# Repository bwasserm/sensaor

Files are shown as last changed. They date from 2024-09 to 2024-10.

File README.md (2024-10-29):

# senSAOr - a sensor SAO

A Simple Add-On (SAO) for a conference badge with a modular sensor port and a reactive multicolor LED.

# Project Goals
* Design and make an SAO in time for Hackaday Supercon 2024
* Make it inexpensive enough and simple enough to make a bunch and trade with others
* Blinky, but more interesting than only blinky
* Cool design
* If writing firmware, write it in Rust
* If using a microcontroller, use RISC-V

# High Level Design

SAO is a microcontroller that reads a sensor from an input pin, and uses the measured voltage to drive the color/brightness/pattern of an LED.
Create ports for multiple different sensors to be used, with the ability to solder in different signal conditioning.
Use ID pins or a solderable resistors to tell firmware how to "read" the sensor and drive the LED in response.

# Expected Behaviors

The inputs are read to set the color of the bottom LED. Every cycle, the colors are clocked one LED up the board, and potentially out to an attached strand of addition WS2812s attached at the top. All inputs are read in [0V, 3.3V] as low to high.

## Red/Green/Blue
These inputs are read to set the base intensity of the LEDs accordingly.

## Speed
This sets the delay between update cycles from fast (low) to slow (high). Full low has no added delay between cycles, and full high has about 1s between cycles.

## Shape
This is the mixture ration between setting the output intensity of the colors based directly on the input (low) vs also mixing in a sine wave (high) to the brightness (off to the intensity set by the color input).

## Phase
When mixing in the sine wave, this delays the mix of the sine wave applied to green and blue relative to red. Low is the same phase of sine wave is applied to all three colors, and high is about 120 degrees of delay to green and 240 degrees of delay to blue.

## ID pins
Currently unused

## I2C
Currently unused. Set as high impedance inputs.

## GPIO\[12\]
Currently unused. Set as high impedance inputs.

## More WS2812
Connect more Neopixels here to continue clocking out colors beyond the three on the SAO.

## SAOAO
Hopefully "standard" SAOAO port to connect an SAOAO.

# Resources
* [Shitty Add-On Version 2.0 Specification](https://docs.google.com/document/u/0/d/1EJqvkkLMAPsQ9VWF5A4elWoi0qMlKyr5Giw5rqRmtnM/mobilebasic?pli=1)
* [Opensource toolchain for WCH CH32V RISC-V 32bit MCU](https://github.com/cjacker/opensource-toolchain-ch32v)
* [ch32-hal](https://github.com/ch32-rs/ch32-hal)
* [Rust on the CH32V003](https://noxim.xyz/blog/rust-ch32v003/)
* [CH32V00X-hal](https://github.com/ch32-rs/ch32v00x-hal)
* [wlink application](https://github.com/ch32-rs/wlink)
* [wlink with CH32V003](https://github.com/ch32-rs/wlink/blob/main/docs/CH32V003.md)
* [CH32V003F4P6-R0 image](https://github.com/openwch/ch32v003/blob/main/SCHPCB/CH32V003F4P6-R0-1v1/image/board1.jpg)
* [CH32V003F4P6-R0 schematic](https://github.com/openwch/ch32v003/blob/main/SCHPCB/CH32V003F4P6-R0-1v1/SCH_PCB/CH32V003F4P6-R0-1v1.pdf)
* [ch32v003.svd](https://github.com/ch32-rs/ch32-rs/blob/main/svd/fixed/ch32v003.svd)
* [CH32V003 Reference Manual](https://www.wch-ic.com/downloads/file/358.html)
* [CH32V003 Processor Manual](https://www.wch-ic.com/downloads/file/369.html)
* [CH32V003 Datasheet](https://www.wch-ic.com/downloads/file/359.html)
* [RISC-V Spec](https://riscv.org/wp-content/uploads/2019/12/riscv-spec-20191213.pdf)
* [SAOAO](https://hackaday.io/project/198060-yo-dawg-sao-introducing-saoao)

# Implementation blog

## Getting rust to build

Getting rust to compile was mostly following the [Rust on the CH32V003](https://noxim.xyz/blog/rust-ch32v003/) blog, with some off-roading. LLVM had already
picked up the support for `rv32ec` (the `e` extension is the core `i` architecture, but with 16 registers instead of 32 for smaller silicon), but rustc didn't know
the riscv32ec-unknown-none-elf target. Eventually I figured out I didn't need to make the hack to rustc either, if I provided a target .json file to build against.
However, having a local copy of llvm and the binary tools was useful, such as for llvm-objdump.

Eventually I found that much of the work on the blog was "done" in the [CH32V00X-hal](https://github.com/ch32-rs/ch32v00x-hal) project, so I cloned that next to this project.
To avoid copying files, I hacked this to link to it. .cargo/config.toml points the target to `ch32v00x-hal/riscv32ec-unknown-none-elf.json`. The target json I copied from the noxim
blog is included for good measure.

I also found that the `-Tmemory.x` and `-Tlink.x` arguments got redundant with the CH32V00X-hal repo and build.rs (adding that repo as a Cargo dep changes things), so it may
require some experimentation.

Note on `memory.x`:
Looking at the memory map, it appears that program flash is a 16KB block starting at address `0x0800 0000`. However, ch32v00x-hal and the noxim blog both define
`FLASH (rx) : ORIGIN = 0x00000000, LENGTH = 16K` at address `0x0000 0000`, which is the `Aliased to Flash or system memory depending on software configuration` block of a much
larger size. This block defaults to flash, and the program counter (`pc`) will default to address `0x0000 0000` when the chip boots. So even though it seems unintuitive, set the `FLASH`
address in `memory.x` to be 0x0. 

I went down an exploratory path using `ch32v00x-hal/link-qkv2.x` instead of finding `link.x`, which required modifying `INCLUDE device.x` to become `INCLUDE svd2rs/device.x`,
after also `cargo install svd2rust`, and running it on [cj32v003.svd](https://github.com/ch32-rs/ch32-rs/blob/main/svd/fixed/ch32v003.svd) to generate `device.x`. However, after
adding in [CH32V00X-hal](https://github.com/ch32-rs/ch32v00x-hal), I found I didn't need this.

## Getting blinky to run

I'm playing with the CH32V003F4P6-R0 dev board, pictured [here](https://github.com/openwch/ch32v003/blob/main/SCHPCB/CH32V003F4P6-R0-1v1/image/board1.jpg), and referencing
the [schematic](https://github.com/openwch/ch32v003/blob/main/SCHPCB/CH32V003F4P6-R0-1v1/SCH_PCB/CH32V003F4P6-R0-1v1.pdf) as well was super handy. Especially because I tried using
PA1 as an arbitrary GPIO pin choice, but it is already tied to the oscillator.

I used the [wlink](https://github.com/ch32-rs/wlink) application with the WLinkE . It turned out to be surprisingly easy to run and use to dump registers and flash. It's not even
necessary to convert the elf file produced by cargo/rustc into an Intel Hex file or a bin first.

```
cargo install wlink
```

* Programming command: `sudo ~/.cargo/bin/wlink -v --chip ch32v003 flash target/riscv32ec-unknown-none-elf/debug/sensaor`
* Get registers command: `sudo ~/.cargo/bin/wlink -v --chip ch32v003 regs`
* Dump the beginning of program flash: `sudo ~/.cargo/bin/wlink -v --chip ch32v003 dump 0x00000000 400`

The sudo is becuase I'm too lazy to figure out which group to add myself to to get permissions to talk to the programmer.

`wlink` also has a serial terminal functionality that works with the WLinkE debugger I'm using. However, my WLinkE isn't showing up as a serial device (`/dev/ttyASM0` or similar),
so I can't connect to that. I'm guessing it's a udev rule I need to update, since `lsusb` indicates multiple modem/serial interfaces on the USB device. Probably an Arch (BTW) config
issue on my end.

Using the LEDs on the dev board, it's important to set the GPIO pins into open drain mode, not push-pull. With the extra resistors from push-pull, not enough current flows to turn
on the LEDs (since they already have resistors installed inline).

### WLink on Windows

On my Windows 10/11 machines, I was getting `Error: USB error: Entity not found` errors when trying to run `wlink status`. This is because the wlink doesn't activate the correct drivers by default.

* See this [github issue](https://github.com/ch32-rs/wlink/issues/5) for an example
* Install [zadig](https://zadig.akeo.ie/)
* Select `WCH-Link (Interface 0)` and install the driver `WinUSB`.

## Reading the ADC to modify the blink

First, I moved the binaries into src/bin/ so I could build multiple at once, and therefore make things easier to have multiple apps in work.

The greatest challenge reading the ADC was finding the right part of the HAL to use. Eventually I found `ch32v00x-hal/src/adc.rs` `OneShot::read()`, but due to not knowing rust's import system well enough, spent way too long getting it to build. Through help, the answer is adding `embedded-hal-02` as a dependency, and `use embedded_hal_02::adc::OneShot;`. While I don't have a great analog source yet, the blink rate does apear to change when I touch the input pin, so I think it might be working.

## Driving the Neopixels

I wanted to use a Neopixel (WS2811/WS2812) library to drive them, but those rely on a timer or SPI implementation for the chip. The hal I'm using for the CH32V003 doesn't implement SPI. After getting annoyed with the traits required to get the existing timer library to work, I figured implementing enough of SPI to write would be easier. With enough time with the manual, and some C examples of setting up SPI on this chip to compare which bits are set in the control registers, I got my neopixel string to change colors.

# Programming tips

Including any `println!()` calls without having the debugger connected and watching the serial port will cause the application to block upon a print.

With serial console:

```
cargo b --release; wlink -v --chip ch32v003 flash .\target\riscv32ec-unknown-none-elf\release\sao --enable-sdi-print --watch-serial
```

Without serial console:

```
cargo b --release; wlink -v --chip ch32v003 flash .\target\riscv32ec-unknown-none-elf\release\sao
```

Note that using `println!()` when sdi print is not enabled or the debugger is not watching serial will cause the program to lock up at the first `println!()`.

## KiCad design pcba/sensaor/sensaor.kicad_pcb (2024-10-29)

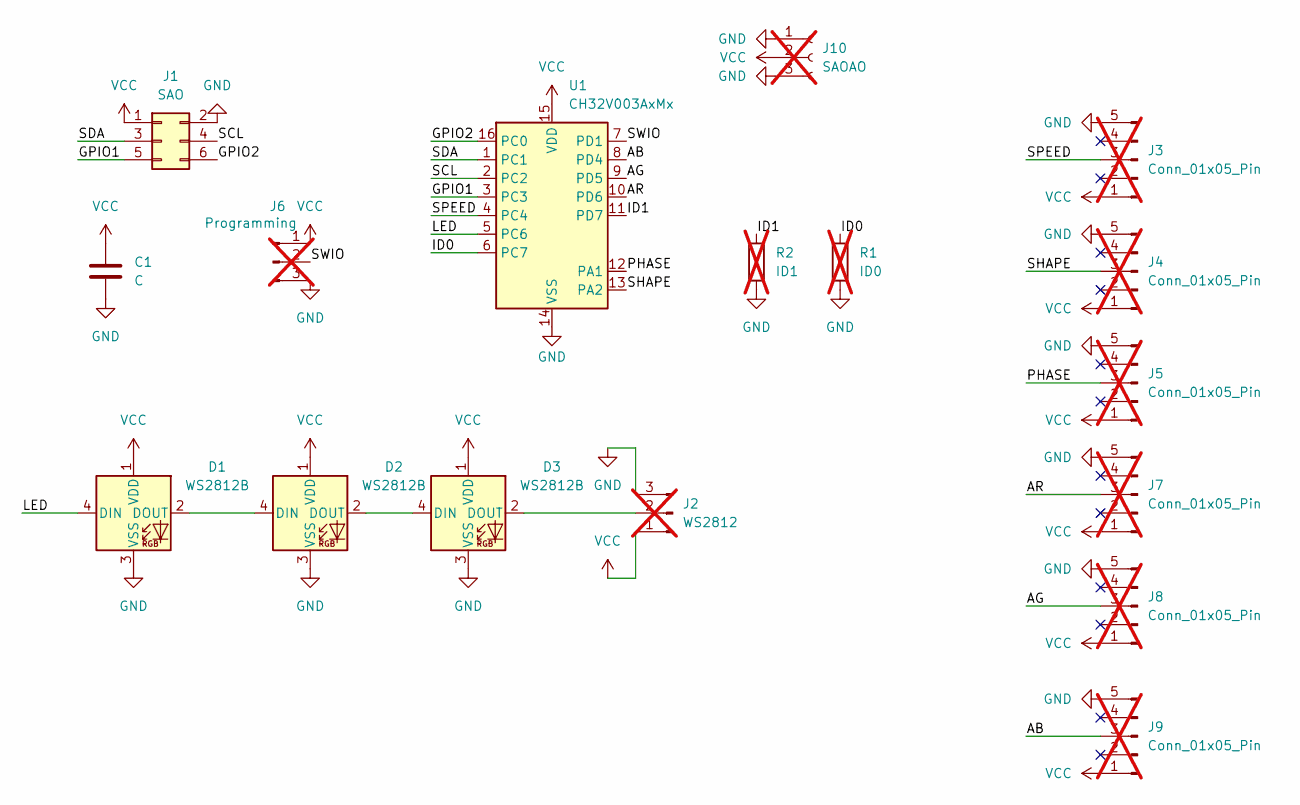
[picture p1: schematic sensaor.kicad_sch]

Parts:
C1: C; C_0603_1608Metric_Pad1.08x0.95mm_HandSolder
D1, D2, D3: WS2812B; LED_WS2812B_PLCC4_5.0x5.0mm_P3.2mm
J1: SAO; IDC-Header_2x03_P2.54mm_Vertical
J2: WS2812; PinHeader_1x03_P2.54mm_Vertical; not fitted
J3, J4, J5, J7, J8, J9: Conn_01x05_Pin; PinHeader_1x05_P2.54mm_Vertical; not fitted
J6: Programming; PinHeader_1x03_P2.54mm_Vertical; not fitted
J10: SAOAO; PinHeader_1x03_P1.27mm_Vertical; not fitted
R1: ID0; C_0402_1005Metric_Pad0.74x0.62mm_HandSolder; not fitted
R2: ID1; C_0402_1005Metric_Pad0.74x0.62mm_HandSolder; not fitted
U1: CH32V003AxMx; SOP-16_3.9x9.9mm_P1.27mm

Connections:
/AB: J9.3, U1.8 (PD4)
/AG: J8.3, U1.9 (PD5)
/AR: J7.3, U1.10 (PD6)
/GPIO1: J1.5, U1.3 (PC3)
/GPIO2: J1.6, U1.16 (PC0)
/ID0: R1.1, U1.6 (PC7)
/ID1: R2.1, U1.11 (PD7)
/LED: D1.4 (DIN), U1.5 (PC6)
/PHASE: J5.3, U1.12 (PA1)
/SCL: J1.4, U1.2 (PC2)
/SDA: J1.3, U1.1 (PC1)
/SHAPE: J4.3, U1.13 (PA2)
/SPEED: J3.3, U1.4 (PC4)
/SWIO: J6.2, U1.7 (PD1)
GND: C1.2, D1.3 (VSS), D2.3 (VSS), D3.3 (VSS), J1.2, J2.3, J3.5, J4.5, J5.5, J6.3, J7.5, J8.5, J9.5, J10.1, J10.3, R1.2, R2.2, U1.14 (VSS)
unnamed: D1.2 (DOUT), D2.4 (DIN)
unnamed: D2.2 (DOUT), D3.4 (DIN)
unnamed: D3.2 (DOUT), J2.2
VCC: C1.1, D1.1 (VDD), D2.1 (VDD), D3.1 (VDD), J1.1, J2.1, J3.1, J4.1, J5.1, J6.1, J7.1, J8.1, J9.1, J10.2, U1.15 (VDD)

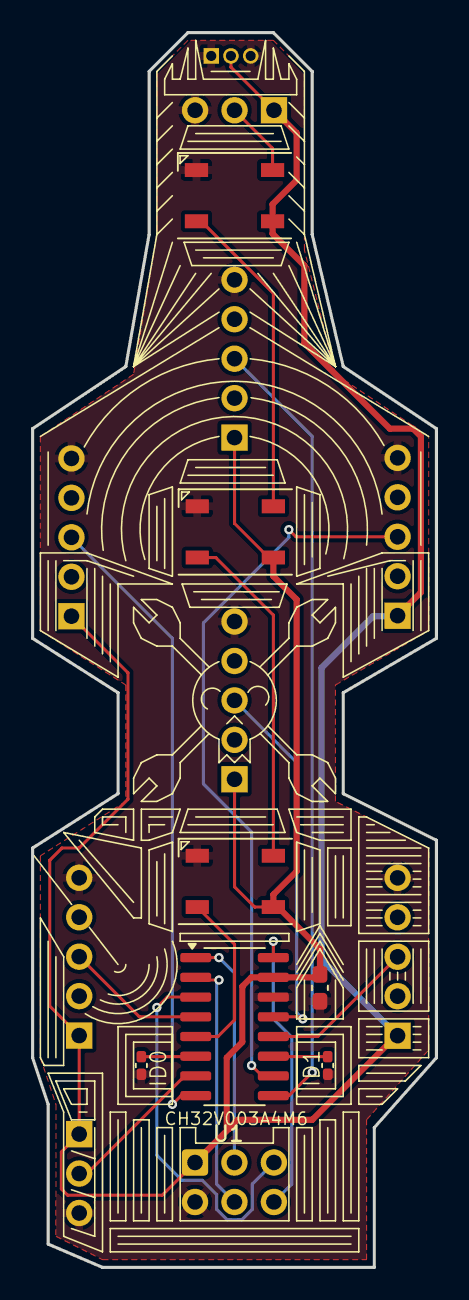
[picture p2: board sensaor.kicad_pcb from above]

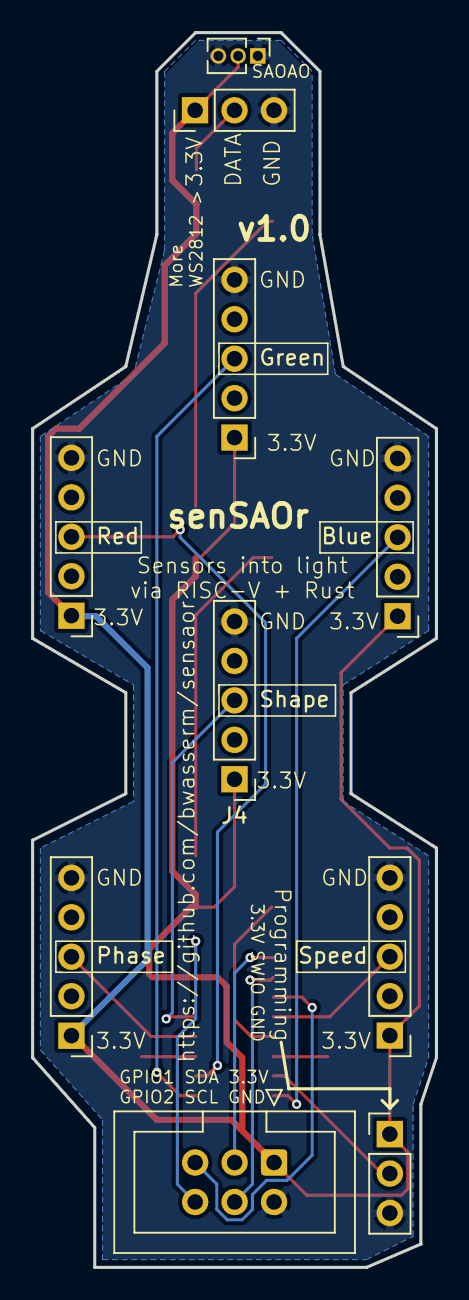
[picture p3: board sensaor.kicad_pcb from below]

Board: 2 copper layers, 26.0 x 79.5 mm, 17 parts (10 on the bottom side), 19 nets.

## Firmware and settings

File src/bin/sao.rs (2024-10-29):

#![no_main]
#![no_std]

use ch32v00x_hal::i2c::{I2c, I2cConfig};
use ws2812_spi::{self, Ws2812};

use embedded_hal_02::adc::OneShot;
use embedded_hal_1::spi;

use smart_leds::{brightness, SmartLedsWrite, RGB8};

use embedded_hal_1::delay::DelayNs;
use panic_halt as _;

use ch32v00x_hal::prelude::*;
use ch32v00x_hal::println;
use ch32v00x_hal::{self as hal};

#[qingke_rt::entry]
fn main() -> ! {
    // Constrain clocking registers
    let p = ch32v0::ch32v003::Peripherals::take().unwrap();

    p.RCC
        .apb2pcenr
        .modify(|_, w| w
            .spi1en().set_bit()
            .adc1en().set_bit()
            .iopaen().set_bit()
            .iopcen().set_bit()
            .iopden().set_bit()
        );
    p.RCC.apb2prstr.modify(|_, w| w.spi1rst().set_bit());
    p.RCC.apb2prstr.modify(|_, w| w.spi1rst().clear_bit());
    p.SPI1.ctlr1.modify(|_, w| {w
        .bidimode()
            .set_bit()
        .bidioe()
            .set_bit()
        .crcen()
            .clear_bit()
        .crcnext()
            .clear_bit()
        .dff()
            .clear_bit()
        .rxonly()
            .clear_bit()
        .ssm()
            .set_bit()
        .ssi()
            .set_bit()
        .lsbfirst()
            .clear_bit()
        .spe()
            .clear_bit()
        .br()
            .variant(2_u8) // 24MHz / 8 => 3Mhz
        .mstr()
            .set_bit()
        .cpha()
            .clear_bit()
        .cpol()
            .clear_bit()
    });
    p.SPI1.ctlr1.modify(|_, w| w.spe().set_bit());
    let mut rcc = p.RCC.constrain();
    let clocks = rcc.config.freeze();

    // Get delay provider
    let mut delay = hal::delay::CycleDelay::new(&clocks);

    let gpioa = p.GPIOA.split(&mut rcc);
    let gpioc = p.GPIOC.split(&mut rcc);
    let gpiod = p.GPIOD.split(&mut rcc);

    let mut adc_red = gpiod.pd6.into_analog();
    let mut adc_green = gpiod.pd5.into_analog();
    let mut adc_blue = gpiod.pd4.into_analog();
    let mut adc_speed = gpioc.pc4.into_analog();
    let mut adc_shape = gpioa.pa2.into_analog();
    let mut adc_phase = gpioa.pa1.into_analog();
    let sda = gpioc.pc1.into_floating_input();
    let scl = gpioc.pc2.into_floating_input();
    let _mosi = gpioc
        .pc6
        .into_alternate()
        .set_speed(ch32v00x_hal::gpio::Speed::Mhz50);
    let mut _id0 = gpioc.pc7.into_pull_up_input();
    let mut _id1 = gpiod.pd7.into_pull_up_input();
    let mut _gpio1 = gpioc.pc3.into_floating_input();
    let mut _gpio2 = gpioc.pc0.into_floating_input();

    let mut adc = hal::adc::Adc::new(p.ADC1, &clocks);
    // let _i2c = I2c::i2c1(p.I2C1, scl, sda, I2cConfig::fast_mode(), &mut rcc, &clocks);
    let spi = SpiDriver::new(p.SPI1);
    let mut ws = Ws2812::new(spi);

    // let mut adc_val: u16 = adc.read(&mut pc4).unwrap();

    const NUM_LEDS: usize = 62;
    let mut led_data = [RGB8 { r: 0, g: 0, b: 0}; NUM_LEDS];
    const LEN_SINE_TABLE: usize = 256;
    let sine_table: [u32; LEN_SINE_TABLE] = [
        128, 131, 134, 137, 140, 143, 146, 149, 152, 155, 158, 162, 165, 167, 170, 173,
        176, 179, 182, 185, 188, 190, 193, 196, 198, 201, 203, 206, 208, 211, 213, 215,
        218, 220, 222, 224, 226, 228, 230, 232, 234, 235, 237, 238, 240, 241, 243, 244,
        245, 246, 248, 249, 250, 250, 251, 252, 253, 253, 254, 254, 254, 255, 255, 255,
        255, 255, 255, 255, 254, 254, 254, 253, 253, 252, 251, 250, 250, 249, 248, 246,
        245, 244, 243, 241, 240, 238, 237, 235, 234, 232, 230, 228, 226, 224, 222, 220,
        218, 215, 213, 211, 208, 206, 203, 201, 198, 196, 193, 190, 188, 185, 182, 179,
        176, 173, 170, 167, 165, 162, 158, 155, 152, 149, 146, 143, 140, 137, 134, 131,
        128, 124, 121, 118, 115, 112, 109, 106, 103, 100, 97, 93, 90, 88, 85, 82,
        79, 76, 73, 70, 67, 65, 62, 59, 57, 54, 52, 49, 47, 44, 42, 40,
        37, 35, 33, 31, 29, 27, 25, 23, 21, 20, 18, 17, 15, 14, 12, 11,
        10, 9, 7, 6, 5, 5, 4, 3, 2, 2, 1, 1, 1, 0, 0, 0,
        0, 0, 0, 0, 1, 1, 1, 2, 2, 3, 4, 5, 5, 6, 7, 9,
        10, 11, 12, 14, 15, 17, 18, 20, 21, 23, 25, 27, 29, 31, 33, 35,
        37, 40, 42, 44, 47, 49, 52, 54, 57, 59, 62, 65, 67, 70, 73, 76,
        79, 82, 85, 88, 90, 93, 97, 100, 103, 106, 109, 112, 115, 118, 121, 124
        ];
    let _adc_max: u32 = adc.max_sample().into();
    // let mut red_data: [u32; NUM_LEDS] = [0; NUM_LEDS];
    // let mut green_data: [u32; NUM_LEDS] = [0; NUM_LEDS];
    // let mut blue_data: [u32; NUM_LEDS] = [0; NUM_LEDS];
        
    // let mut data = [RGB8 { r: 0, g: 0, b: 0}; NUM_LEDS];
    // loop {
        //     for j in 0..(256 * 5) {
    //         for i in 0..NUM_LEDS {
    //             data[i] = _wheel((((i * 256) as u16 / NUM_LEDS as u16 + j as u16) & 255) as u8);
    //         }
    //         ws.write(brightness(data.iter().cloned(), 16)).unwrap();
    //         delay.delay_ms(5);
    //         println!("{} {} {}", data[0], data[1], data[2]);
    //     }
    // }
    
    // let scaling: u32 = 1;
    let mut time: u32 = 0;
    loop {
        let phase_delay_a: u32 = adc.read(&mut adc_phase).unwrap();
        let phase_delay = phase_delay_a >> 3;
        let sine_red = sine_table[time as u8 as usize];
        let sine_green = sine_table[(time + phase_delay) as u8 as usize];
        let sine_blue = sine_table[(time + 2 * phase_delay) as u8 as usize];
        let shape_val: u32 = adc.read(&mut adc_shape).unwrap();
        let dc_offset = _adc_max - shape_val;

        let red_val_a: u32 = adc.read(&mut adc_red).unwrap();
        // red_val_a = x / 1024 (x / 2^10)
        // sine_red = x / 256 (x / 2^8)
        // shape_val = x / 1024 (x / 2^10)
        // red_sine_part = x / 2^16
        let red_sine_part = (red_val_a * sine_red * shape_val) >> 12;
        // red_val_a = x / 1024 (x / 2^10)
        // dc_offset = x / 1024 (x / 2^10)
        // red_dc_part = x / 2^16
        let red_dc_part = (red_val_a * dc_offset) >> 4;
        // red_val = x / 256 (x / 2^8)
        let red_val = (red_sine_part + red_dc_part) >> 8;

        let green_val_a: u32 = adc.read(&mut adc_green).unwrap();
        let green_sine_part = (green_val_a * sine_green * shape_val) >> 12;
        let green_dc_part = (green_val_a * dc_offset) >> 4;
        let green_val = (green_sine_part + green_dc_part) >> 8;

        let blue_val_a: u32 = adc.read(&mut adc_blue).unwrap();
        let blue_sine_part = (blue_val_a * sine_blue * shape_val) >> 12;
        let blue_dc_part = (blue_val_a * dc_offset) >> 4;
        let blue_val = (blue_sine_part + blue_dc_part) >> 8;
        
        let delay_val: u32 = adc.read(&mut adc_speed).unwrap();
        let delay_ms: u32 = adc.max_sample() as u32 - delay_val;

        for i in (1..NUM_LEDS).rev() {
            led_data[i] = led_data[i - 1].clone();
        }
        led_data[0] = RGB8 { r: (red_val) as u8,
                             g: (green_val) as u8,
                             b: (blue_val) as u8};
        ws.write(brightness(led_data.iter().cloned(), 32)).unwrap();
        for _ in 0..delay_ms {
            time = time.wrapping_add(1);
            delay.delay_ms(1);
        }
        // println!("{red_val_a}\t{red_val}\t{delay_val}\t{phase_delay}\t{shape_val}  {dc_offset}");
        // println!("t: {time}\nLED: {} {} {}\ndelay_ms: {delay_ms} phase: {phase_delay_a} shape: {shape_val}", led_data[0], led_data[1], led_data[2]);
    }
}

/// Input a value 0 to 255 to get a color value
/// The colours are a transition r - g - b - back to r.
fn _wheel(mut wheel_pos: u8) -> RGB8 {
    wheel_pos = 255 - wheel_pos;
    if wheel_pos < 85 {
        return (255 - wheel_pos * 3, 0, wheel_pos * 3).into();
    }
    if wheel_pos < 170 {
        wheel_pos -= 85;
        return (0, wheel_pos * 3, 255 - wheel_pos * 3).into();
    }
    wheel_pos -= 170;
    (wheel_pos * 3, 255 - wheel_pos * 3, 0).into()
}

#[derive(Debug)]
struct SpiDriver {
    spi: ch32v00x_hal::pac::SPI1,
}

impl SpiDriver {
    pub fn new(spi: ch32v00x_hal::pac::SPI1) -> Self {
        Self { spi }
    }
}

impl spi::ErrorType for SpiDriver {
    type Error = spi::ErrorKind;
}

impl spi::SpiBus for SpiDriver {
    fn read(&mut self, _words: &mut [u8]) -> Result<(), Self::Error> {
        todo!()
    }

    fn write(&mut self, words: &[u8]) -> Result<(), Self::Error> {
        while self.spi.statr.read().txe().bit_is_clear() {}
        for word in words {
            self.spi.datar.write(|w| unsafe { w.bits(*word as u32) });
        }
        Ok(())
    }

    fn transfer(&mut self, _read: &mut [u8], _write: &[u8]) -> Result<(), Self::Error> {
        todo!()
    }

    fn transfer_in_place(&mut self, _words: &mut [u8]) -> Result<(), Self::Error> {
        todo!()
    }

    fn flush(&mut self) -> Result<(), Self::Error> {
        todo!()
    }
}

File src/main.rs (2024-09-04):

#![no_std]
#![no_main]

use hal::println;
use panic_halt as _;

use ch32v00x_hal as hal;
use ch32v00x_hal::prelude::*;
use qingke::riscv;

#[qingke_rt::entry]
fn main() -> ! {
    hal::debug::SDIPrint::enable();

    // println!("Hello world from ch32v003!");
    // To ensure safe access to peripherals, all types are !Copy singletons. The
    // PAC makes us pass these marker types around to access the registers
    let p = ch32v0::ch32v003::Peripherals::take().unwrap();

    let mut rcc = p.RCC.constrain();
    let _clocks = rcc.config.freeze();

    let gpiod = p.GPIOD.split(&mut rcc);
    // let gpioa = p.GPIOA.split(&mut rcc);

    let mut led1 = gpiod.pd6.into_open_drain_output();
    // let mut led2 = gpioa.pa2.into_open_drain_output();
    let mut led2 = gpiod.pd4.into_open_drain_output();

    loop {
        // led1.toggle();
        // led2.toggle();
        led1.toggle();
        led2.toggle();
        // println!("led toggle");

        unsafe {
            riscv::asm::delay(4800000);
        }
    }
}

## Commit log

2024-09-06 Move applications so I can build both bins. Add adc demo to practice reading the ADC, and have it change the blink rate accordingly.
2024-09-07 Update readme for adc
2024-09-18 Implement SPI and WS2812 rainbow
2024-09-18 Fix comment for clock conversion
    [rainbow.rs]
2024-09-19 Add PCBA, needs finishing
    [sensaor.kicad_pcb, sensaor.kicad_sch]
2024-09-20 Update PCB
    [sensaor.kicad_pcb, sensaor.kicad_sch]
2024-09-22 Shrink board and fix DRC
    [sensaor.kicad_pcb, sensaor.kicad_sch]
2024-09-22 Add ground pours, update silkscreen
    [sensaor.kicad_pcb, sensaor.kicad_sch]
2024-09-22 Moving some traces
    [sensaor.kicad_pcb, sensaor.kicad_sch]
2024-09-22 Moved a dimension
    [sensaor.kicad_pcb]
2024-09-22 Updates from review feedback, shrunk board more
    [sensaor.kicad_pcb, sensaor.kicad_sch]
2024-10-01 I think this is what I ordered as the v0.9 boards
    [sensaor.kicad_pcb]
2024-10-01 Redesign board into more of a carrier shape
    [sensaor.kicad_pcb, sensaor.kicad_sch]
2024-10-01 Fix ground plane connections
    [sensaor.kicad_pcb]
2024-10-01 Update silkscreens
    [sensaor.kicad_pcb]
2024-10-02 Improved LED driving behavior, disabled I2C
2024-10-03 Add SAOAO connector, tweak some placements
    [sensaor.kicad_pcb, sensaor.kicad_sch]
2024-10-03 Adjustments from PCBA review
    [sensaor.kicad_pcb]
2024-10-26 More debug notes in readme, fixed math so all 6 inputs should work to set colors correctly
    [sao.rs]
2024-10-26 Update and comment out debug prints, and update README with the behaviors..
2024-10-29 Adjusted layout. Ordered 30x v1.0 boards
    [sensaor.kicad_pcb]
